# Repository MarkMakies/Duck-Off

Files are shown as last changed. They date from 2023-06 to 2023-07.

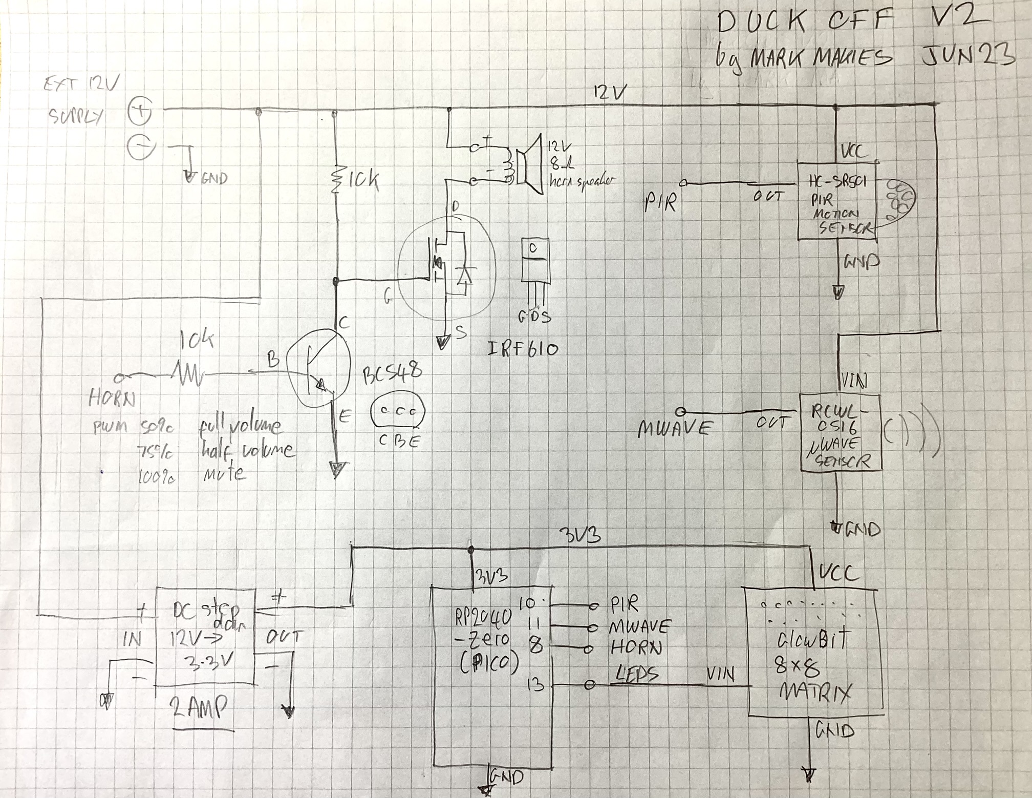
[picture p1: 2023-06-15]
Schematic.jpg

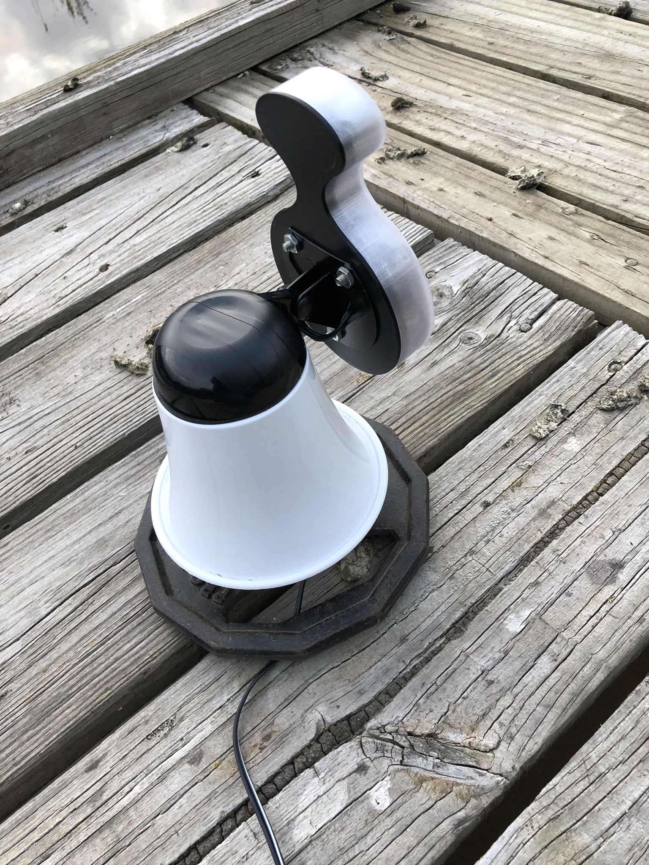
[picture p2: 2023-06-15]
Assembled and installed.jpg

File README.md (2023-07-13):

# Duck Off


**Electronic Duck Repeller**

## What's it do?
Scares ducks off my jetty when they get too close so I don't have to cleanup endless amounts of duck poo!

## How does it work?  
It detects presence using PIR and microwave sensors which triggers a two stage sound and light show.
It uses a 12V 5W horn speaker and 8x8 matrix of LEDs to strobe.

## Build Instructions
https://core-electronics.com.au/projects/duck-off-duck-repellent-device/

## Parts
- RP2040 Pico board (or anything that runs Micropyhton
- GlowBit 8x8 Matrix of LEDs
- RCWL-0516 Microwave sensor
- HC-SR501 PIR Motion Sensor
- 2x 10k resistors
- BC547 Bipolar (or whatever is lying around)
- IRF610 FET (or whatever is lying around)
- 12V 5W Horn Speaker
- 12V -> 3.3V 2A stepdown 
- Power source (On standby expect 35mA, but pushing 2A when triggered) 

## 3D Printing
- Design files in FreeCAD format
- Models in step format
- Traslucent PETG used for front- pay particular attention to first layer.  It must only be one layer thick, but also use 150% flow, otherwise not as watertight

## Usage
- After powering on move away and avoid changes for 60 seconds whilst sensors initialise.
- A funky count down will signal that it is armed (single green LED).
- Upon trigger, for either 10 seconds, or 20 if creature has not moved on, an increasingly louder noise and brighter strobes.  
- Then a 60 second lockout (single red LED).
- When it rearms, as well as the green single LED, another will indicate how many time it has been triggered since last power cycle (up to 63)

## Videos
- On the jetty:  https://youtube.com/shorts/f2WUhRsC7lQ?feature=share
- On the desk:   https://youtube.com/shorts/twOLctHPTis?feature=share

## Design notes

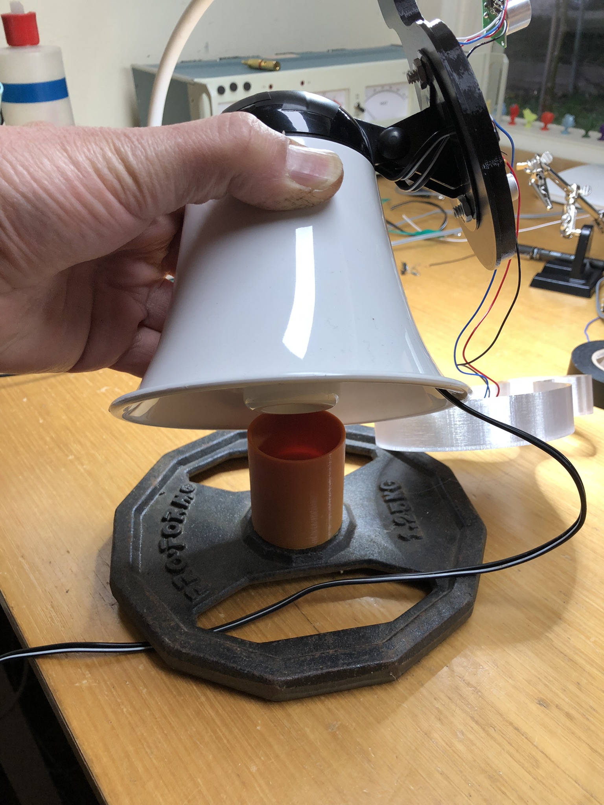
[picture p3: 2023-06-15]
Speaker attached to weight.jpg

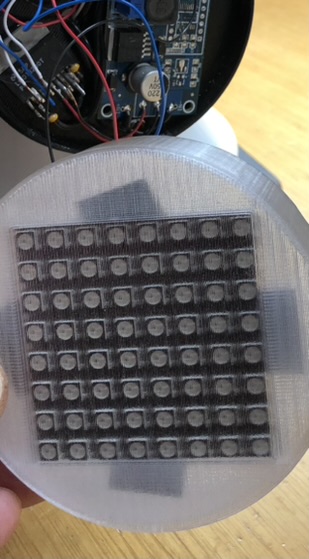
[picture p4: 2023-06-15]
LEDs behind PETG front cover.jpg

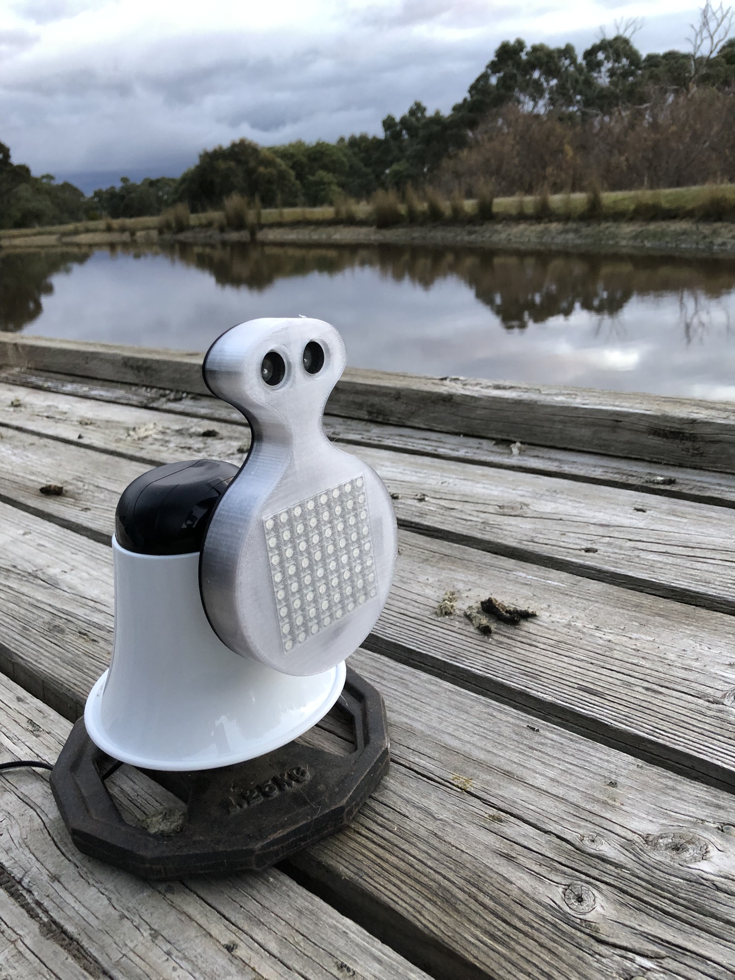
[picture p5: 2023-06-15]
Version 1 used a range finder.jpg

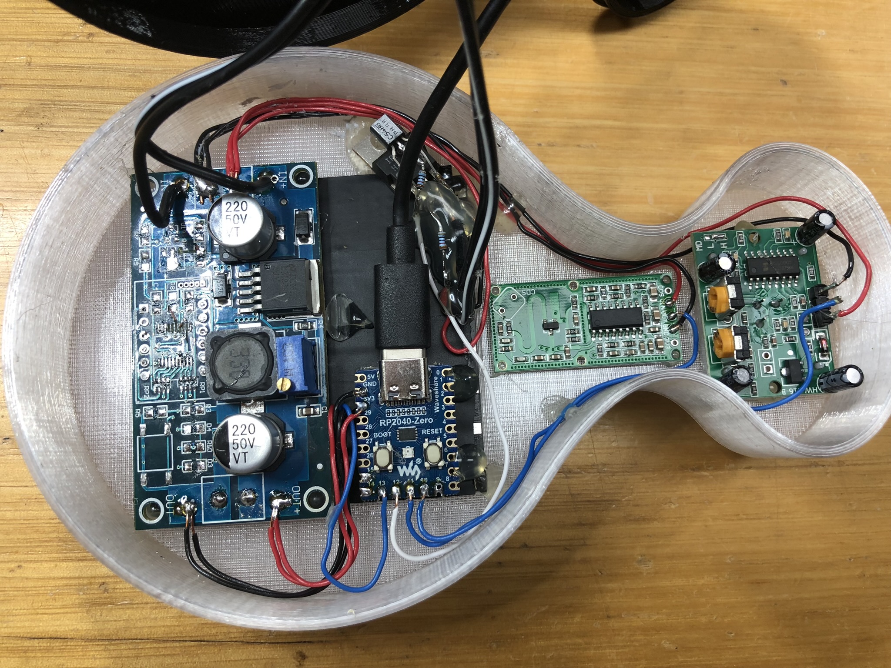
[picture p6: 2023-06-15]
Innards.jpg

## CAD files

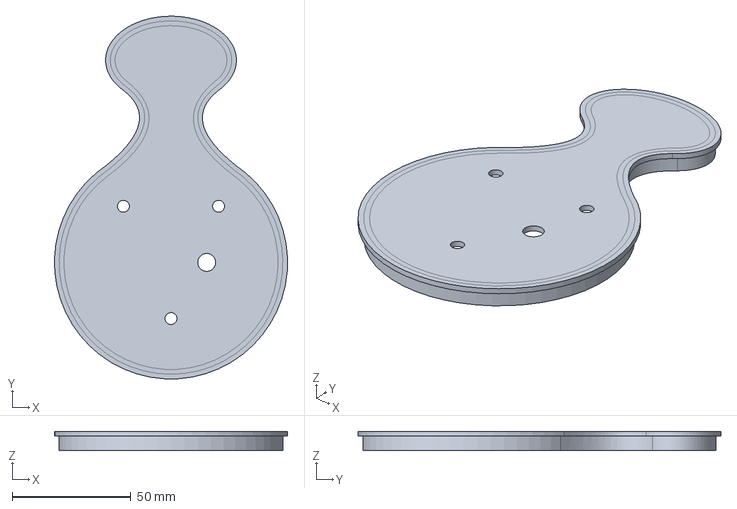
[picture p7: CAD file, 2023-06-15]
DuckOff4.FCStd
97.9 x 152.4 x 8.00 mm

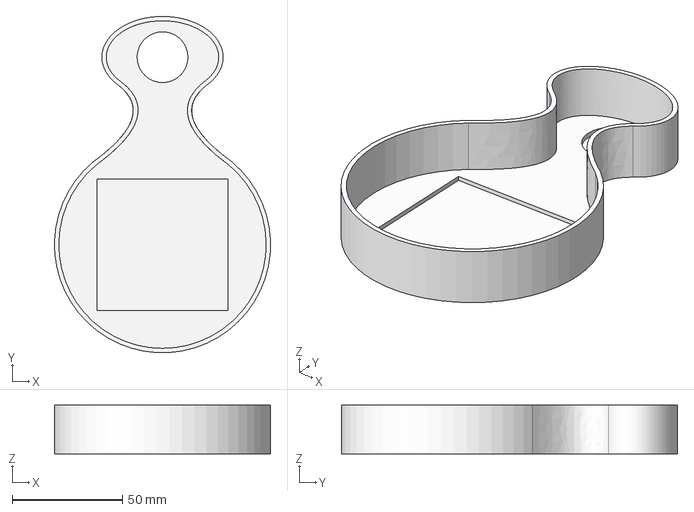
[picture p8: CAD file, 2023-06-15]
DuckOff4-Front.step
97.9 x 152.4 x 22.0 mm

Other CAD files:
DuckOff4-Back.step
DuckOff4-Back.3mf
DuckOff4-Front.3mf

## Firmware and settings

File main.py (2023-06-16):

###############################################################################
#
# Duck Off Thing
#   using RP2040 Pico, 8x8 LED matrix, PIR movement sensor, microwave presence 
#   sensor, DC to DC step down, simple 2 transistor speaker driver
# v1.01 8/5/23 first try using ultrasonic range finder and H-bridge to drive 
# v2.01 1/6/23 new enclosure, + PIR sensor, + mWave sensor.  ditched ultrasonic
# v2.02 15/6/23 using PlayLists for light and sound, added visual trigger count
# v2.03 16/6/23 new interrupt driven sensor poll, retriggerable recovery state
#
###############################################################################

# Output to drive transistor pair for 12V 5W horn speaker (NOTE PWM inverted)
from machine import Pin, PWM, Timer
Phorn = PWM(Pin(8, Pin.OUT))
Phorn.freq(1000)
Phorn.duty_u16(2**16 - 1)       # this NEEDS to be done ASAP

# HC-SR501 PIR Motion Sensor, after (re)trig -> 2s high then 2s lockout
Ppir = Pin(11, Pin.IN)

# RCWL-0516 Microwave sensor, 1s high then appears to have a 5 sec lockout
Pmwave = Pin(10, Pin.IN)

# GlowBit 8x8 Matrix of LEDs
Pleds = Pin(13,Pin.OUT)

from time import sleep_ms, ticks_ms
from neopixel import NeoPixel as NP
from math import log10
import gc

###############################################################################
# LIGHTS

numPixels = 64
LEDs = NP(Pleds, numPixels)
''' Pixel Map
00 01 02 03 04 05 06 07
08 09 10 11 12 13 14 15
16 17 18 19 20 21 22 23
24 25 26 27 28 29 30 31
32 33 34 35 36 37 38 39 
40 41 42 43 44 45 46 47
48 49 50 51 52 53 54 55
56 57 58 59 60 61 62 63
'''
BorderPix = [0,1,2,3,4,5,6,7,15,23,31,39,47,55,63,62,61,60,59,58,57,56,48,40,
            32,24,16,8]
SnakePix =  [9,10,11,12,13,14,22,21,20,19,18,17,25,26,27,28,29,30,38,37,36,35,
            34,33,41,42,43,44,45,46,54,53,52,51,50,49] 

def Fill(R, G, B):
    for i in range(numPixels):
        LEDs[i] = ((R,G,B))
    NP.write(LEDs)

def Border(R, G, B, Dur):  
    if Dur == 0:
        for i in BorderPix:
            LEDs[i] = ((R,G,B))
        NP.write(LEDs)
    else:
        for i in BorderPix:
            LEDs[i] = ((R,G,B))
            NP.write(LEDs)
            sleep_ms(Dur)

def Strobe(R, G, B, Freq, Dur_ms):
    start = ticks_ms()
    delay = int(1 / Freq / 1000 / 2)  # 2 cycles, in ms
    while ticks_ms() < start + Dur_ms:
            Fill(0,0,0)
            sleep_ms(delay)
            Fill(R,G,B)
            sleep_ms(delay)

###############################################################################
# SOUND

def Tone(Freq, Vol):
    # vol expected to be between 0 and 10
    # freq between 30 and 3000
    # higher freq, greater power required, hence AdjVol formula.  testing shows:
    # @ 10Hz   PWM between 10 and 100  log10(10)=1 log10(100)=2           [1 ~ 2]
    # @ 100Hz  PWM between 50 and 500  log10(50)=1.7 log10(500)=2.7       [2 ~ 3]
    # @ 1kHz   PWM between 400 and 9000   log10(400)=2.6 log10(9000)=3.9  [3 ~ 4] 
    if Vol == 0:
        Phorn.duty_u16(2**16 - 1)
    else:
        AdjFreq = int(min(max(Freq, 30), 3000))
        AdjVol = int( 10 ** (log10(AdjFreq) + log10(Vol)))
        Phorn.freq(AdjFreq)
        Phorn.duty_u16(2**16 - AdjVol)

def Beep(Freq, Vol, Dur):
    Tone(Freq, Vol)
    sleep_ms(Dur)
    Tone(Freq, 0)

def Play(I):
    Fstart, Fend, Vstart, Vend, R, G, B, StrobeFreq, Duration = I
    # Blocking Play routine, pass tuple with
    # Frequency start and end or same for no change (30 - 3000)
    # Volume start and end or same (0 - 10)
    # Frequency and Volume in either direction
    # R, G, B values for strobe fill (0 - 255)
    # Strobe frequency (< 50), dont expect accuracy
    # duration of play in ms (10 - 1000) 
    
    loopDelay = 10
    StrobeFlipCount = max(1, int(1000 / StrobeFreq / 2 / loopDelay))

    numCycles = Duration / loopDelay
    freqStep = (Fend - Fstart) / numCycles
    volStep = (Vend - Vstart) / numCycles

    F, V = Fstart, Vstart 
    count = 1
    flip = True

    while count <= numCycles:
        Tone(F, V)
        if flip:
            Fill(R, G, B)
        else:
            Fill(0,0,0)
        F += freqStep
        V += volStep
        count += 1
        if count % StrobeFlipCount == 0:
            flip = not flip

        sleep_ms(loopDelay)

    Tone(0,0)
    Fill(0,0,0)

RampList = [(30, 30, 0, 2,       100, 100, 100,   20,      1000),
            (30, 50, 2, 5,       100, 100, 100,   20,      1000),
            (200, 100, 2, 4,     100, 0, 0,       30,      1000),
            (800, 300, 6, 2,     0, 100, 0,       10,       200),
            (100, 300, 2, 7,     0, 0, 100,       10,       200),
            (100, 300, 6, 2,     155, 155, 155,   50,       200),
            (1060, 60, 5, 7,     100,100,100,     5,        100)]

BlastList = [(3000, 2000, 10, 5,   255,255,255,    50,      400),  
            (1000, 3000, 10, 5,    255,255,255,   100,      600), 
            (30, 50, 10, 8,        255, 0, 0,      40,     1000),
            (1000, 1500, 10, 10,   0, 255, 0,      10,      600),
            (3000, 30, 10, 8,      0, 0, 255,       5,     1000),
            (100, 50, 1, 10,       255, 255, 255,  25,      500),
            (100, 50, 1, 10,       255, 255, 255,  15,      500),
            (100, 50, 1, 10,       255, 255, 255,  10,      500),
            (60, 3000, 5, 10,      255,0,0,        10,      100),
            (30, 3000, 10, 10,     255,255,255,    40,      200)]

#for i in RampList: Play(i)  
#for i in BlastList:  Play(i)  

###############################################################################
# SENSOR reads
# no luck getting reliable interrupts working, so instead poll based on 
# 100ms interrupts to ensure a long Plays don't miss a sensor change

def cbTimer(timer1):
    global SensorDetect
    SensorDetect = Ppir.value() or Pmwave.value()

###############################################################################
# INITIALISE
# We need to wait for the sensors (30-60s) so lets do a fancy count down

StartDelay = 60

Fill(0,0,0)
Border(0,10,0,0)

for i in SnakePix:
    LEDs[i] = ((10,10,10))
NP.write(LEDs)

CountDelay = int(StartDelay * 1000 / len(SnakePix))
for i in SnakePix:
    LEDs[i] = ((0,0,0))
    if not 50 <= i <= 54:
        sleep_ms(CountDelay)
    else:
        sleep_ms(int(CountDelay-(28*20))) # adj for 28 pixels @ 20ms each 
    NP.write(LEDs)
    if i == 54:   
        Beep(200, 1, 100)
        Border(20,0,0,20)        
    if i == 53:
        Border(0,0,0,0)
        Beep(400, 2, 100)
        Border(30,0,0,20)
    if i == 52:
        Border(0,0,0,0)
        Beep(800, 3, 100)
        Border(50,0,0,20)
    if i == 51:
        Border(0,0,0,0)
        Beep(1200, 4, 100)
        Border(100,0,0,20)
    if i == 50:
        Border(0,0,0,0)
        Beep(1500, 5, 100)
        Border(200,0,0,20)     
    if i == 49:
        Tone(0,0)
        Strobe(255,255,255,6,500)

Fill(0,0,0)
Tone(0,0)

###############################################################################
# START main state machine loop
#
# Init:   LED[0] = white   remain in this state until no sensor inputs 
# Armed:  LED[0] = green   waiting for a SensorDetect trigger
#                          in this mode, a LED between 1 and 63 will be blue
#                          to indicate how many triggers have occured since 
#                          last power cycle (up to 63)
# Ramp:   flashing matrix  Ramp up the noise, playing list of sounds & strobes
#                          monitor for retrigger and if so move to Blast 
#                          after tRamp time. if no retigger move to Recovery
# Blast   flashing matrix  Shock and awe hopefully, for period tBlast
# Recover LED[0] = red     stay in this state for at least tRevover AFTER last 
#                          DetectSensor event. solves problem of getting up 
#                          at 3am for a stuck sensor.  if recovery was 
#                          retriggered LED[7] = Red to indicate the problem

SensorDetect = False
timer1 = Timer(period=100, callback=cbTimer)    # start periodic sensor reads
sleep_ms(200)    # ensure first clean read prior to entering main state machine 

tRamp = 10      # ramp time (s), if playlist is too short (in time) repeat last
tBlast = 10     # Blast Time
tRevover = 60   # lockout recovery time

State = 'Init'
lState = ''

TrigCount = 1

while True:   
    if State != lState:
        lState = State
        print(State)

    if State == 'Init':
        LEDs[0] = ((10,10,10))
        NP.write(LEDs)
        if not SensorDetect:
            State = 'Armed'
    
    elif State == 'Armed':   
        LEDs[0] = ((0,10,0))
        LEDs[TrigCount] = ((0,0,20))
        NP.write(LEDs)

        if SensorDetect:
            State = 'Ramp'
            TrigCount = min(63, TrigCount + 1)
            RampCount = 0
            StateTime = ticks_ms()
            ReArmed = False
            BlastEnable = False

    elif State == 'Ramp':
        Play(RampList[RampCount])
        RampCount = min(len(RampList) - 1, RampCount + 1)

        if not SensorDetect: 
            ReArmed = True
        if ReArmed and SensorDetect: 
            BlastEnable = True

        if StateTime + (1000 * tRamp) < ticks_ms():  
            if BlastEnable or SensorDetect:
                State = 'Blast'
                BlastCount = 0
                StateTime = ticks_ms()
            else:
                Tone(0,0)
                StateTime = ticks_ms()
                State = 'Recover'

    elif State == 'Blast':

        Play(BlastList[BlastCount])
        BlastCount = min(len(BlastList) - 1, BlastCount + 1)

        if StateTime + (1000 * tBlast) < ticks_ms():
            Tone(0,0)
            StateTime = ticks_ms()
            State = 'Recover'

    elif State == 'Recover':
        LEDs[0] = ((20,0,0))
        NP.write(LEDs)
        if StateTime + (1000 * tRevover) < ticks_ms():
            State = 'Armed'
            LEDs[7] = ((0,0,0))
        if SensorDetect:                # reset timet if detect in wait period
            StateTime = ticks_ms()
            LEDs[7] = ((20,0,0))
            NP.write(LEDs)

    if State != 'Ramp' and State != 'Blast': sleep_ms(50)
    gc.collect()
